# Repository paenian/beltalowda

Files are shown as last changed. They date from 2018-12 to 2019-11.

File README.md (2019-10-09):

# beltalowda
Large Beltesian 3D printer - that is a cartesian with a belt-driven Z axis.

# Status: Working! in testing.

# Todo:
 - Top Rail - add a top rail on the other end of the Y beam, and double-up the X axis motors.  While it works, the machine isn't rigid enough at the top end of the Y rail.  Works fine for ~100mm tall parts, but more would be better.
 
 - Thicker bed surface, test other surfaces - the bed isn't quite rigid enough.  Making it thicker should help.  Joining, bending and moving a thicker belt aren't the easiest, but hopefully there's a happy mediun somewhere.

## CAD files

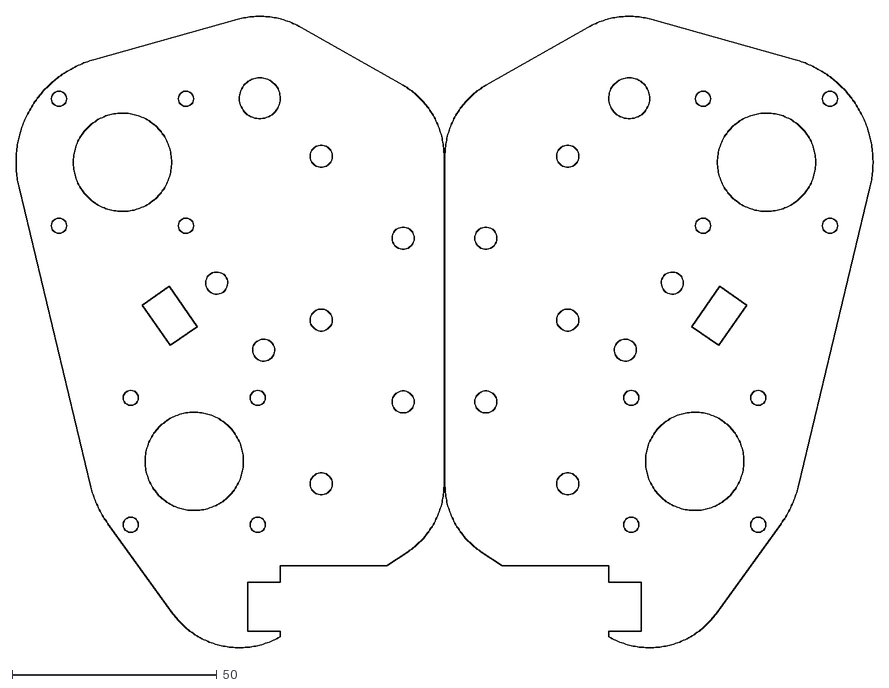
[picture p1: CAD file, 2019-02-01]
dxfs/spacer_plates.dxf
209.3 x 154.2

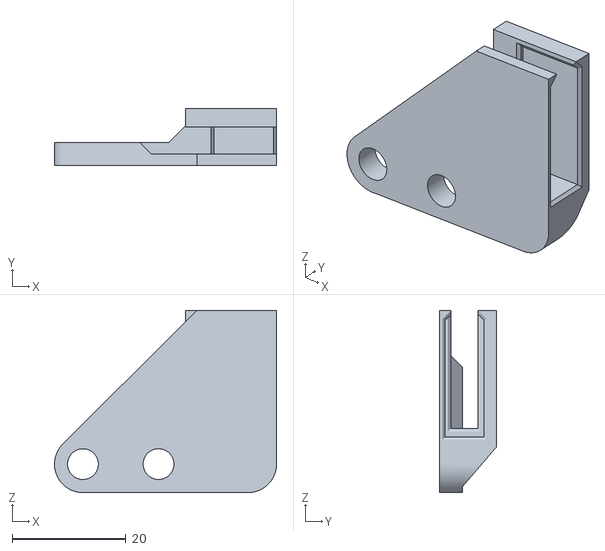
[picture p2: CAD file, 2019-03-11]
external_stls/endstop_mount.stl
39.0 x 10.0 x 32.0

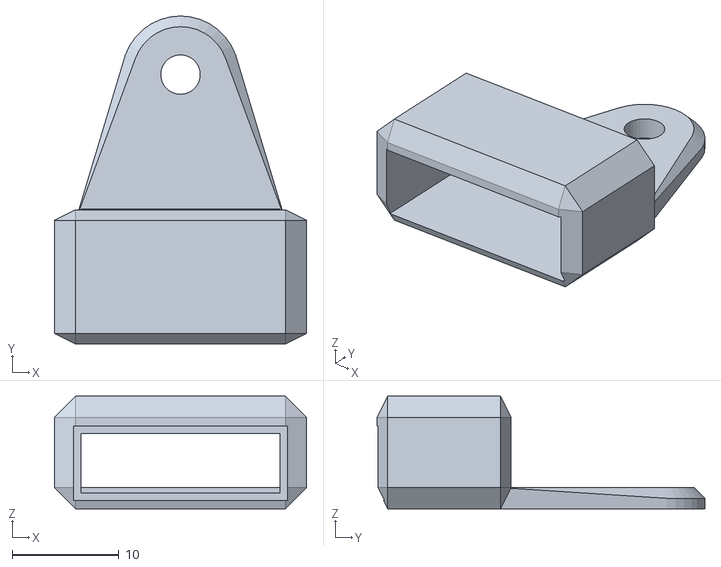
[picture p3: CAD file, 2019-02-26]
stls/endstop_mount.stl
23.7 x 30.8 x 10.6

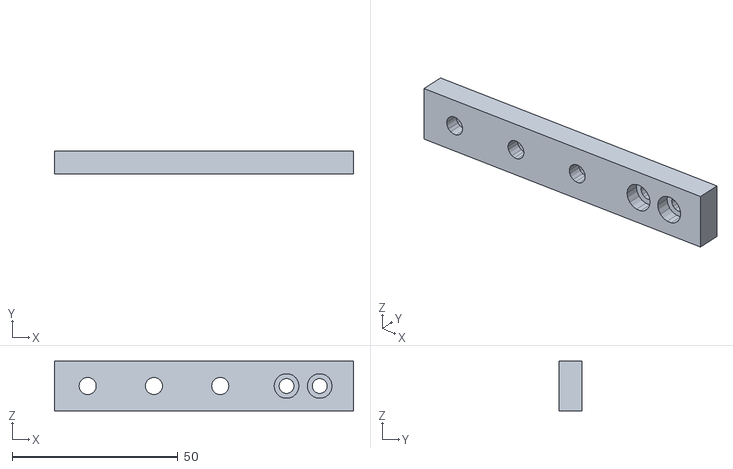
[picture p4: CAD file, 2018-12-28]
temp_stls/power_mount.stl
90.2 x 6.90 x 15.0

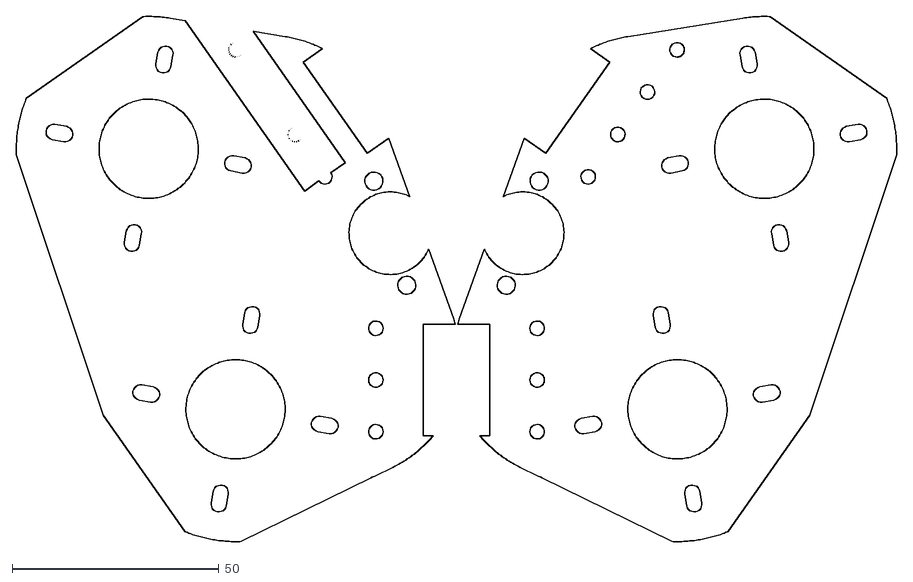
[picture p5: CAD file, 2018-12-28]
dxfs/y_plates.dxf
212.9 x 127.0

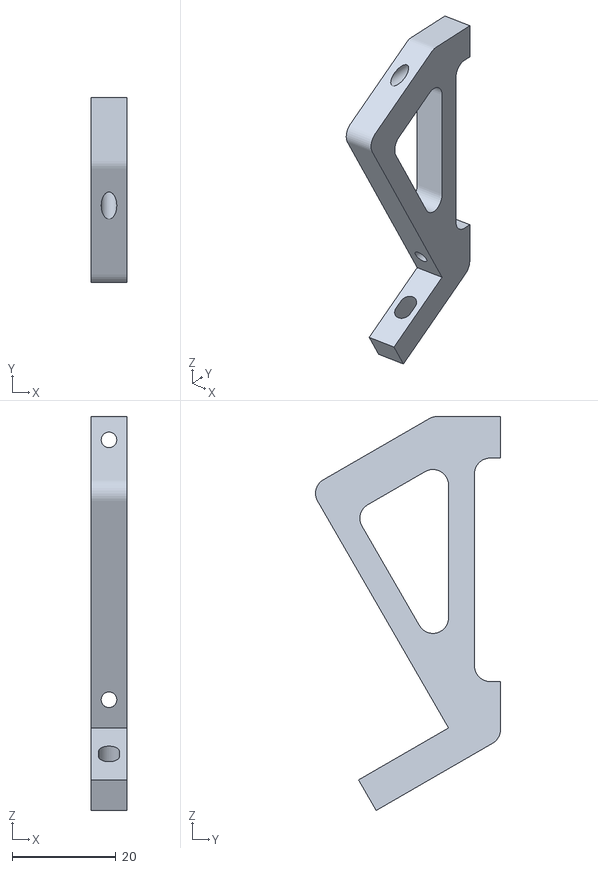
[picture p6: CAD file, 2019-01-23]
external_stls/Smart_LCD_kinnitus.stl
7.00 x 35.6 x 75.8

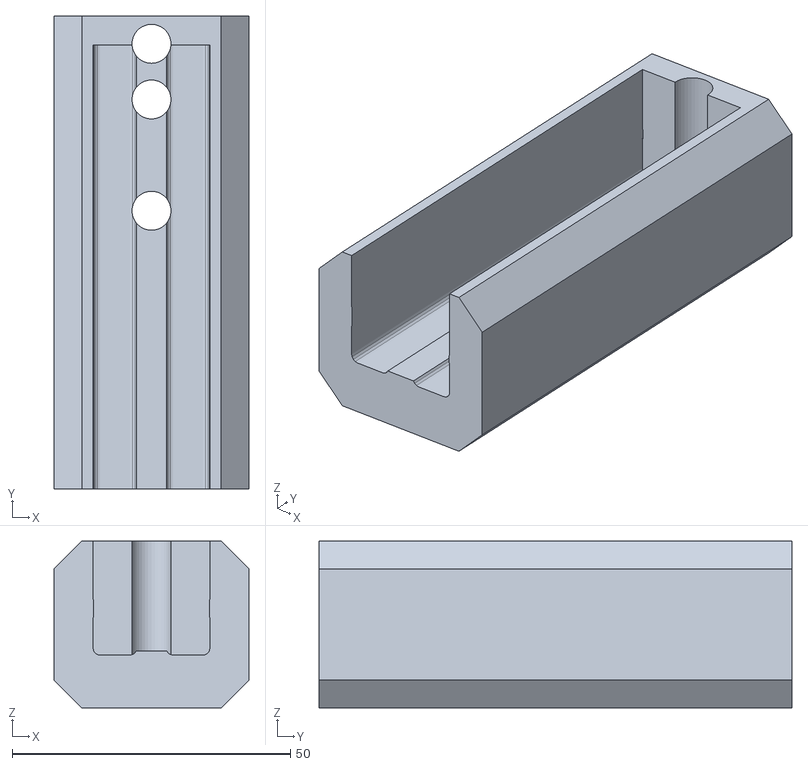
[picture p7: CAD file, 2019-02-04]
stls/drill_guide.stl
35.0 x 85.0 x 30.0

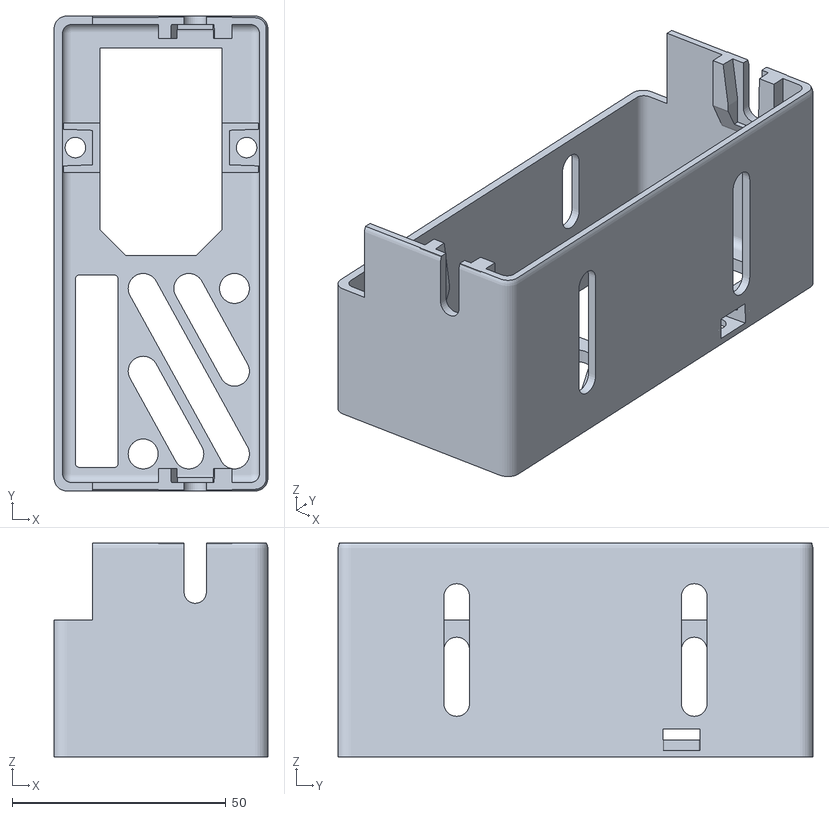
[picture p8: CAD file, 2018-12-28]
temp_stls/PowerSupply.stl
50.0 x 111.0 x 50.0

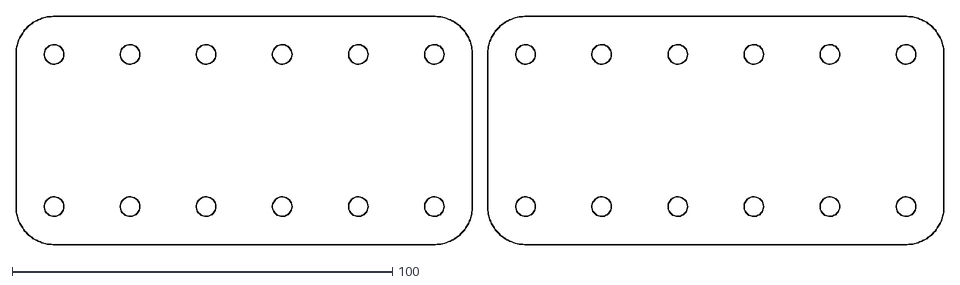
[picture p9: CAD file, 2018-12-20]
dxfs/bed_plate.dxf
244.0 x 60.0

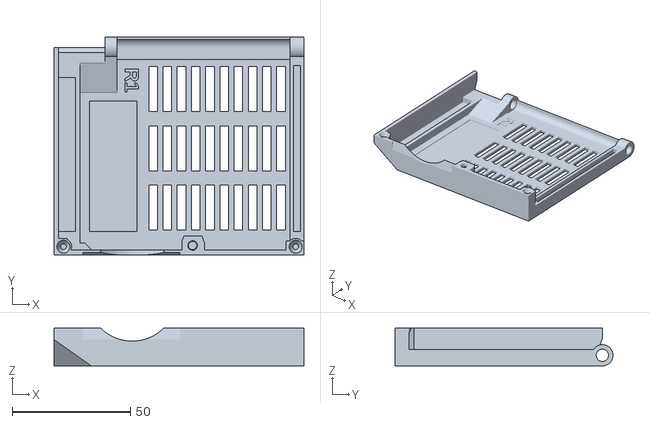
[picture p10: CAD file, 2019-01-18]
external_stls/Einsy_Door_with_fan.stl
105.5 x 92.0 x 16.0

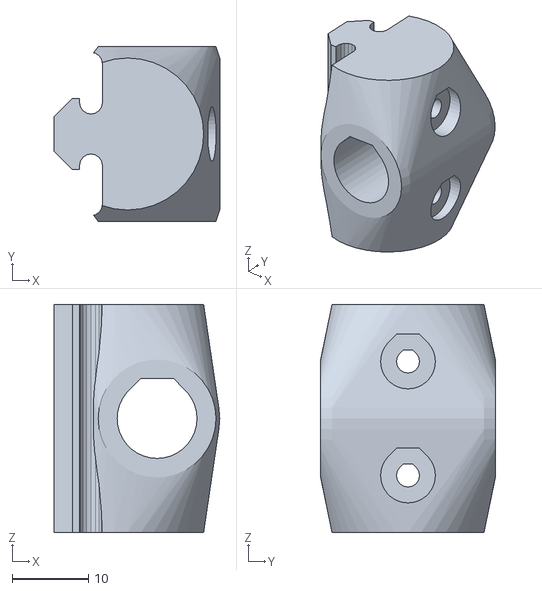
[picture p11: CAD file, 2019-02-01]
stls/z_slider.stl
21.8 x 23.0 x 30.0

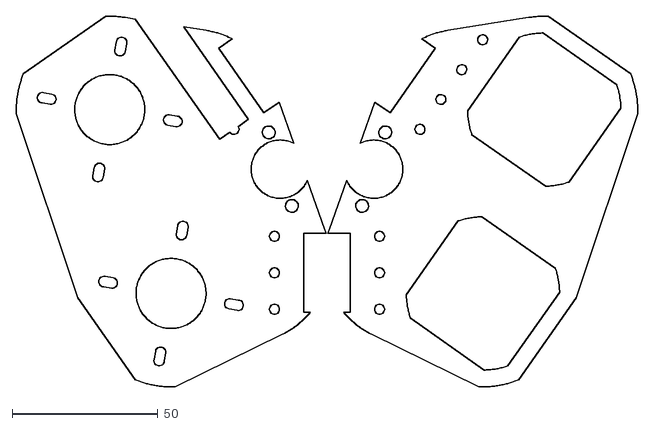
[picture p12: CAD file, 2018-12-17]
dxfs/ab2_y_plates.dxf
212.9 x 127.0

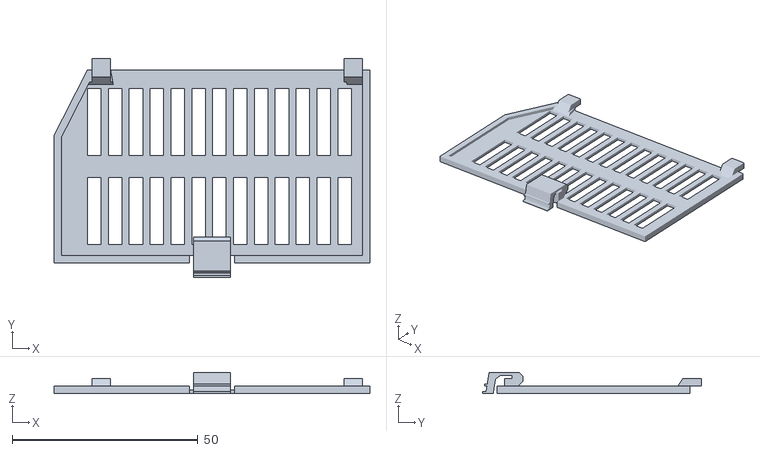
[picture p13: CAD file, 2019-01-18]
external_stls/New_Pi_Zero_Door.STL
85.0 x 58.9 x 5.66

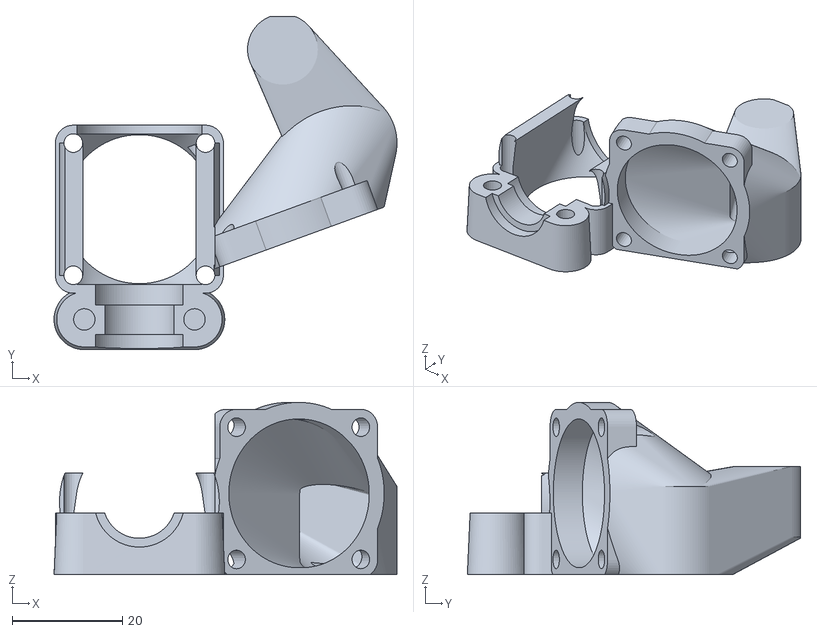
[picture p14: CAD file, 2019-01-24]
stls/hotend_fan_mounts.stl
62.2 x 60.5 x 31.2

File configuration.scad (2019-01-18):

in = 25.4;
mdf_wall = 6.5;
mdf_tab = 15;

wall = 5;

screw_slop = .2;
slop = .2;
laser_slop = -.1;

beam = 20;

layer_height=.2;

pulley_rad = 13/2;
pulley_flange_rad = 18/2;

//bed thicknesses
bed_inset = 4;
bed_thick = 2.3;
heater_thick = 2.2;
insulation_thick = 1;
bed_lift = heater_thick+insulation_thick;

eccentric_rad = 7.3/2;
eccentric_flange_rad = 11/2;

belt_thick = 9;
belt_width = 1.5;

//belt drive variables
small_teeth = 13;
motor_shaft_rad = 5/2+.2;
big_teeth = 41;
gear_thick = 13;
distance_between_axles = 37;
circular_pitch = 360*distance_between_axles/(small_teeth+big_teeth);


//motor size and placement variables
motor_w = 42;
motor_r = 52/2;
motor_screw_sep = 31;

//standard screw variables
m3_nut_rad = 6.01/2+slop;
m3_nut_height = 2.4;
m3_rad = 3.1/2+slop;
m3_cap_rad = 3.5;
m3_cap_height = 2;
m3_sq_nut_rad = 7.9/2;

m4_nut_rad = 7.66/2+slop;
m4_nut_height = 3.2;
m4_rad = 4/2+slop;
m4_cap_rad = 7/2+slop;
m4_cap_height = 2.5;

m5_nut_rad = 8.79/2;
m5_sq_nut_rad = (8*sqrt(2)+slop/2)/2;
m5_nut_rad_laser = 8.79/2-.445;
m5_nut_height = 4.7;
m5_rad = 5/2+slop;
m5_rad_laser = 5/2-.1;
m5_cap_rad = 10/2+slop;
m5_cap_height = 3;
m5_washer_rad = 11/2+slop;

ten24_rad = (.19*in/2+slop);
ten24_cap_rad = (.361*in/2+slop);
ten24_cap_height = .101*in+slop;
ten24_nut_rad = ((3/8*in)*cos(180/6))/2;
ten24_sq_nut_rad = ((3/8*in)*sqrt(2))/2+slop/2;

ten24_nut_height = 1/8*in+slop;

ten24_rad_laser = ten24_rad+laser_slop/2;
ten24_sq_nut_rad_laser = ten24_sq_nut_rad+laser_slop/2;
ten24_sq_nut_flat = 9.5;
ten24_sq_nut_flat_laser = ten24_sq_nut_flat+laser_slop;

//x axis variables
linear_rail_width = 12;
linear_rail_height = 8;
linear_rail_carriage_width = 27;
linear_rail_carriage_height = 10;
linear_rail_carriage_length = 34.7;
linear_rail_carriage_offset = 3+(linear_rail_carriage_height-linear_rail_height)/2;
linear_rail_carriage_screw_sep_w = 20;
linear_rail_carriage_screw_sep_l = 20;
linear_rail_screw_offset = 12.5;
linear_rail_screw_sep = 25;


//makes all the holes have lots of segments
$fs=.5;
$fa=.1;


//machine configuration parameters
y_rail_sep = 300;

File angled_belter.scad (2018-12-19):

include <configuration.scad>
use <functions.scad>
use <herringbone_gears.scad>

length = 500;
angle = 35;

bed_plate = in*20;
roller_rad = 2.375/2*in;
roller_rod_rad = 5;
roller_drop = 1;
roller_len = in*14;
roller_offset_front = roller_rad+10;
roller_span = 340;
roller_inside_rad = 2.075/2*in-.05;


bearing_rad = 26/2+.125;
bearing_rad = 32/2+.125;    //switch everything to 12mm rods?  Or keep the rollers on 10mm?
bearing_thick = 8;
bearing_thick = 10;
bearing_inset = in;

//belt drive variables
small_teeth = 13;
motor_shaft_rad = 5/2+.2;
big_teeth = 41;
gear_thick = 13;
distance_between_axles = 37;
circular_pitch = 360*distance_between_axles/(small_teeth+big_teeth);

//x axis
x_rod_rad = 6;
x_rod_sep = motor_w+x_rod_rad*4;
x_bearing_flange = 31.5;
x_bearing_flange_rad = 42/2;
x_bearing_rad = 21/2;

back_flange_rad = 36.5/2;
back_nut_rad = 20/2;
back_screw_sep = 26.4;

//x_nut_rad = 10.3/2;
//x_nut_screw_rad = 16/2;

linear_rail_width = 12;
linear_rail_height = 8;




echo(big_teeth/small_teeth);

bracket_thick = 6;

z_rear_offset = 100;
bed_lift = roller_rod_rad+roller_rad; //in*1/16; //put a little insulation under the bed beams

chamfer = 1.5;

part = 5;
mirror = 0;

if(part == 1){
    echo("Print 2 sets of corner brackets");
    translate([beam+.5,0,0]) mirror([1,0,0]) side_bracket(feet=false, corner=true);
    translate([-beam-.5,0,0]) side_bracket(feet=false, corner=true);
}

if(part == 1.5){
    echo("Cut 2 sets of corner brackets");
    projection(){
        translate([beam+.5,0,0]) mirror([1,0,0]) side_bracket(feet=false, corner=true);
        translate([-beam-.5,0,0]) side_bracket(feet=false, corner=true);
    }
}

if(part == 2){
    echo("print both spacer plates");
    translate([-beam*2.4,0,0]) spacer_plate();
    mirror([1,0,0]) translate([-beam*2.4,0,0])  spacer_plate();
}

if(part == 2.5){
    echo("Lasercut both spacer plates");
    projection() {
        translate([-beam*2.355,0,0]) spacer_plate();
        mirror([1,0,0]) translate([-beam*2.355,0,0])  spacer_plate();
    }
}

if(part == 3){
    y_plate();
}

if(part == 3.5){
    projection() {
        translate([-beam*.5,0,0]) y_plate();
        mirror([1,0,0]) translate([-beam*.5,0,0]) y_plate(front=true);
    }
}

if(part == 33){
    y_plate(front = true);
}

if(part == 33.5){
    projection() y_plate(front = true);
}

if(part == 4){
    echo("Print 3 roller mounts!");
    mirror([0,0,1]) roller_mount();
}

if(part == 5){
    echo("Print 1 roller drive mounts!");
    mirror([0,0,1]) roller_drive_mount();
}

if(part == 6){
    echo("Print 1 roller drive gear!");
    mirror([0,0,1]) motor_drive_gear();
}

if(part == 7){
    echo("Print one y gantry");
    y_gantry();
}

if(part == 8){
    echo("Print one y endcap");
    endcap();
}

if(part == 9){
    echo("Print one extruder assembly");
    extruder();
}

if(part == 10){
    echo("Print 6ish feet");
    rubber_foot();
}

if(part == 11){
    echo("Print 4 12mm clamps");
    smooth_rod_clamp(rad = x_rod_rad);
}

if(part == 12){
    echo("Print 2 10mm clamps");
    smooth_rod_clamp(rad = rod_rad);
}


if(part == 100){
    assembled();
}
module assembled(){
    frame();
    
    #rods_and_rails();
    
    //side brackets
    *for(i=[0]) for(j=[0,1]) mirror([j,0,0])
        translate([-length/2-bracket_thick/2,i*(length/2-beam*3),0]) rotate([0,-90,0]) rotate([0,0,-90]) render() side_bracket(feet=true);
    
    //corner brackets
    for(i=[0,1]) for(j=[0,1]) mirror([j,0,0]) mirror([0,i,0])
        translate([-length/2-bracket_thick/2,length/2,beam]) mirror([i,0,0]) rotate([0,-90,0]) rotate([0,0,-90]) render() side_bracket(feet=true, corner=true);
    
    for(i=[0,1]) mirror([i,0,0]) translate([-length/2+beam+bracket_thick/2,0,beam*1.5]) rotate([0,90,0]) {
        render() spacer_plate();
    } 
    
    //y axis
    translate([0,x_offset,beam*1.5]) rotate([0,90,0]) {
        render() y_plate(front = false);
        render() translate([0,0,bracket_thick]) y_plate(front = true);
    }
}

module frame(){
    //base
    for(i=[0,1]) mirror([i,0,0]) translate([length/2-beam/2,-length/2,0]) rotate([0,90,0]) rotate([-90,0,0]) render() beam_2060(height = length, v=false);
      
      //don't think this is necessary - the feet will handle the separation.  Or maybe should have this, but no feet...
    for(i=[0,1]) mirror([0,i,0]) translate([-length/2,length/2+beam/2,0]) rotate([0,90,0]) rotate([0,0,0]) render() beam_2060(height = length, v=false);
        
    //bottom 'feet'
    *for(i=[-1,0,1]) translate([-length/2,i*length/2,-beam*2]) rotate([90,0,0]) rotate([0,90,0]) render() beam_2040(height = length, v=false);
    
    //bed beams
    for(j=[1.5]) for(i=[0:6]) translate([-length/2,roller_offset_rear+roller_rad+beam+i*beam*2,beam*2*j]) rotate([90,0,0]) rotate([0,90,0]) render() beam_2040(height = length, v=false);
}

module smooth_rod_clamp(rad = 5, inset=.125){
    screw_sep  = rad + m5_cap_rad;
    screw_height = 9;
    echo(wall);
    difference(){
        union(){
            translate([0,0,rad]) rotate([90,0,0]) hull(){
                cylinder(r=rad+wall, h=beam-2, center=true);
                cylinder(r=rad+wall-1, h=beam, center=true);
            }
            
            for(i=[0,1]) mirror([i,0,0]) translate([screw_sep,0,0]) hull() {
                cylinder(r=m5_rad+wall, h=screw_height+1);
            }
        }
        
        rotate([90,0,0]) hull(){
            cylinder(r=rad+slop, h=beam+1, center=true);
            translate([0,rad,0]) rotate([0,0,180]) cap_cylinder(r=rad+slop, h=beam+1, center=true);
        }
        
        //screwholes
        for(i=[0,1]) mirror([i,0,0]) translate([screw_sep,0,0]) {
            cylinder(r=m5_rad+slop, h=screw_height*3, center=true);
            translate([0,0,screw_height]) cylinder(r=m5_cap_rad+slop, h=wall*3);
        }
        
        //flatten the bottom
        translate([0,0,-50+inset]) cube([100,100,100], center=true);
    }
}

//this goes on the end of the Y axis and tensions the belt.
module endcap(length = 29){
    min_rad = wall/2;
    difference(){
        union(){
            minkowski(){
                cube([linear_rail_width+wall, linear_rail_height+wall, length+wall], center=true);
                sphere(r=min_rad, $fn=6);
            }
            
            //belt pulley mount
            translate([0,-linear_rail_height/2-wall/2,0]) rotate([90,0,0]) cylinder(r1=linear_rail_width/2+wall, r2=m5_rad+.75, h=wall+bracket_thick);
        }
        
        //rail cutout
        translate([0,0,-wall]) cube([linear_rail_width+slop*4, linear_rail_height+slop*4, length], center=true);
        
        //tensioner
        translate([0,0,length/2+wall]){
            translate([0,0,-wall*2+m5_nut_height+1+.25]) cylinder(r=m5_rad, h=length);
            
            translate([0,0,-wall*2]){
                cylinder(r1=m5_nut_rad+.25, r2=m5_nut_rad, h=m5_nut_height+1, $fn=6);
            
                //place to insert the nut
                hull(){
                    translate([0,0,-length-wall]) cylinder(r=m5_nut_rad+1, h=.1);
                    cylinder(r1=m5_nut_rad+.25, r2=m5_nut_rad, h=.1, $fn=6);
                }
            }
        }
        
        //belt nut and shaft
        translate([0,-linear_rail_height/2,0]) rotate([90,0,0]){
            cylinder(r1=m5_nut_rad+.25, r2=m5_nut_rad, h=m5_nut_height+1, $fn=6);
            
            //place to insert the nut
            hull(){
                translate([0,0,-linear_rail_height-wall]) rotate([0,0,180]) cap_cylinder(r=m5_nut_rad+1, h=.1);
                cylinder(r1=m5_nut_rad+.25, r2=m5_nut_rad, h=.1, $fn=6);
            }
            
            //shaft
            rotate([0,0,180]) cap_cylinder(r=m5_rad, h=50, center=true);
        }
    }
}
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

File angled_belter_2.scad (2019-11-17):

include <configuration.scad>
use <functions.scad>
use <herringbone_gears.scad>

length = 500;
angle = 35;

//roller variables
roller_rad = 2.375/2*in;
roller_rod_rad = 5;
roller_drop = 1;
roller_len = in*14;
roller_span = 340;
roller_inside_rad = 2.075/2*in-.075;

//roller bearings - 10mm rods right now.
bearing_rad = 26/2+.15;
//bearing_rad = 32/2+.125;    //switch everything to 12mm rods?  Or keep the rollers on 10mm?
bearing_thick = 8;
bearing_inset = in;

//roller drive variables
small_teeth = 13;
motor_shaft_rad = 5/2+.2;
big_teeth = 61;
gear_thick = 13;
distance_between_axles = 37;
circular_pitch = 360*distance_between_axles/(small_teeth+big_teeth);

//bracket variables
bracket_thick = 6;
chamfer = 1.5;

back_flange_rad = 36.5/2;
back_nut_rad = 20/2;
back_screw_sep = 26.4;

//extruder variables
screw_mount_rad = 5;
screw_mount_screw_sep = 20;

//positioning variables
x_rail_offset_rear = [0,-length/2-beam/2,0];
x_rail_offset_front = x_rail_offset_rear + [0,71,23];

roller_offset_rear = [0,x_rail_offset_front[1] + roller_rad+23,beam*1.5+roller_rod_rad];
roller_offset_front = [0,length/2-roller_rad-beam,beam*1.5+roller_rod_rad];

x_motor_offset = x_rail_offset_rear+[0,motor_w/2+linear_rail_width+wall/2,beam*1.5+motor_w/2];



y_beam_offset = x_motor_offset + [0,motor_w/2, motor_w/2];
y_beam_inset = 9;
y_motor_offset = [-motor_w/2-beam/2, motor_w/2, 0];
y_pulley_offset = y_motor_offset[0];
//The Motor is dependent on the beam - this is an offset from the beam.
y_bracket_hole_lift = linear_rail_carriage_height+14.5;

bed_height = roller_rad+roller_rod_rad+3;
bed_height = beam*2;
bed_offset_rear = -89;

extruder_offset = y_beam_offset - [0,motor_w*1.5,motor_w/2];

part = 21;

if(part == 1){
    projection(){
        rotate([0,90,0]) translate([-length/2+beam,0,beam/2+.1]) spacer_plate_drive();
        rotate([0,-90,0]) translate([length/2-beam,0,beam/2+.1]) spacer_plate_drive();
    }
}

if(part == 2){
    projection(){
        rotate([0,90,0]) translate([-length/2+beam,0,-35]) y_plate(front = false);
        rotate([0,-90,0]) translate([length/2-beam,0,-35]) y_plate(front = true);
    }
}

if(part == 9){
    projection(){
        translate([beam*3.1,0,0]) bed_plate();
        translate([-beam*3.1,0,0]) bed_plate();
    }
}

if(part == 5){
    y_plate_bracket(shift = 0);
}

if(part == 6){
    y_plate_bracket(shift = 1);
}

if(part == 7){
    y_gantry();
    translate([0,16,-bracket_thick/2]) groovemount_screw_clamp();
}

if(part == 77){
    translate([0,16,-bracket_thick/2]) groovemount_clamp_fan();
}

if(part == 8){
    y_tensioner();
}

if(part == 10){
    bed_clamp();
}

if(part == 11){
    bed_rear_support();
}

if(part == 12){
    bed_front_support();
}

if(part == 20){
    mirror([0,0,1]) roller_drive_mount();
}

if(part == 21){
   mirror([0,0,1]) motor_drive_gear();
}

if(part == 22){
    mirror([0,0,1]) roller_mount();
}

if(part == 100){
    assembled();
}

module assembled(){
    frame();
    
    rods_and_rails();
    
    //corner brackets
    for(i=[0,1]) for(j=[0,1]) mirror([j,0,0]) mirror([0,i,0])
        translate([-length/2-bracket_thick/2,length/2,beam]) mirror([i,0,0]) rotate([0,-90,0]) rotate([0,0,-90]) render() side_bracket(feet=true, corner=true);
    
    spacer_plate_drive();
    spacer_plate_idler();
    
    //y axis
    translate([0,x_offset,beam*1.5]) rotate([0,90,0]) {
        render() y_plate(front = false);
        render() translate([0,0,bracket_thick]) y_plate(front = true);
    }
}

module frame(){
    //base square
    for(i=[0,1]) mirror([i,0,0]) translate([length/2-beam/2,-length/2,0]) rotate([0,90,0]) rotate([-90,0,0]) render() beam_2060(height = length, v=false);
    for(i=[0,1]) mirror([0,i,0]) translate([-length/2,length/2+beam/2,0]) rotate([0,90,0]) rotate([0,0,0]) render() beam_2060(height = length, v=false);
    
    //bed beams
    for(i=[0:6]) translate([-length/2,bed_offset_rear+i*40,bed_height+beam]) rotate([90,0,0]) rotate([0,90,0]) render() beam_2040(height = length, v=false);
}

module rods_and_rails(solid = 0, z_rollers=true, draw_y_beam = true){
    //x rails
    translate(x_rail_offset_rear+[0,0,beam*1.5+linear_rail_height/2]) rotate([0,90,0]) rotate([0,0,90]) linear_rail();
    translate(x_rail_offset_front+[0,0,beam*1.5+linear_rail_height/2]) rotate([0,90,0]) rotate([0,0,90]) rotate([0,0,angle]) {
        linear_rail();
        translate([-beam/2,-beam/2-linear_rail_height/2,-(length-beam*2-bracket_thick*2-1)/2]) {
            beam_2040(height = length-beam*2-bracket_thick*2-1);
            //beam screwholes
            for(i=[-beam/2, beam/2]) translate([i,0,-beam*2]) cylinder(r=m5_rad, h=length+beam);
        }
    }
    
    //x axis
    translate(x_motor_offset) rotate([0,90,0]) {
        cylinder(r=4, h=length, center=true);
        if(solid != 1) {
            for(i=[0,1]) mirror([0,0,i]) translate([0,0,length/2-beam]) motor_holes(slot=0);
            
            translate([0,0,bracket_thick]) mirror([0,0,1]) rotate([0,0,90+angle/2]) backlash_nut();           
        }
    }
    
    //y axis   
    translate(y_beam_offset) rotate([0,90,0]) rotate([0,0,angle]) {
        if(solid != 1) {
            //y rail
            translate([0,length/2-y_beam_inset,0]) rotate([90,0,0]) linear_rail(solid = solid, beam = draw_y_beam);
            %translate([0,motor_w+37,0]) rotate([0,0,-90]) y_gantry();
            
            translate(y_motor_offset) motor_holes(slot=0);
        }
    }
    
    //z rollers
    if(z_rollers == true){
        for(i=[roller_offset_rear,roller_offset_front]) translate(i) rotate([90,0,0]) rotate([0,90,0]) {
            cylinder(r=roller_rad, h=roller_len, center=true);
            cylinder(r=roller_rod_rad, h=length, center=true);
        }
    
        //z motor
        z_angle = 25;
        translate(roller_offset_rear+[length/2-beam,0,0])
        rotate([z_angle,0,0]) translate([0,0,distance_between_axles]) rotate([-z_angle,0,0])
        rotate([0,90,0]) motor_holes(slot=0);
    }
    
    echo("roller sep = ");
    echo(roller_offset_front - roller_offset_rear);
    echo("Belt Length = ");
    echo((roller_offset_front - roller_offset_rear)[1] * 2 + 2*3.14159*roller_rad);
}


module motor_drive_gear(){
    translate([distance_between_axles+1,0,0]) gear1(gear1_teeth = small_teeth, circular_pitch=circular_pitch, gear_height=gear_thick);
}

module roller_drive_mount(wall = 3){
    %motor_drive_gear();
    
    radius = gear_radius(big_teeth, circular_pitch);
    outer_radius = gear_outer_radius(big_teeth, circular_pitch);
    
    gear_chamfer_radius = (outer_radius - radius) / tan(45);
    
    lift = gear_thick+1;
    
    difference(){
        union(){
            
            //roller mount
            translate([0,0,lift-.05]) roller_mount();
            //gear
            chamfered_herring_gear(height=gear_thick, number_of_teeth=big_teeth, circular_pitch=circular_pitch, teeth_twist=-1);
            //connect the two
            translate([0,0,gear_thick-.05]) cylinder(r1=radius, r2=roller_inside_rad+wall, h=lift-gear_thick+.1);
        }
        
        //hollow out a path upwards
        translate([0,0,-.1]) cylinder(r1=bearing_rad+wall*3, r2=bearing_rad+wall*2, h=lift+1);
        
        //reopen the tightener holes for the set screws
        translate([0,0,lift-.05]) for(i=[60:360/3:359]) rotate([0,0,i]) translate([0,0,wall*3]) {            
            //access hole
            rotate([0,0,0]) rotate([0,-90-13,0]) rotate([0,0,-90]) cap_cylinder(r=m5_rad+.5, h=50);
        }
    }
}
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

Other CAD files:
dxfs/ab2_spacer_plates.dxf
external_stls/Einsy-base_modified_with_door.stl
stls/roller_drive_gear.stl
dxfs/corner_bracket_pair.dxf
bdp.scad
belter.scad
cooling_fan_mount.scad
dxfs/side_plate.dxf
dxfs/y_front_plate.dxf
external_stls/rpi-zero-frame.stl
extrusion_mounts.scad
functions.scad
herringbone_gears.scad
stls/bed_front_support.stl
stls/bed_side_support.stl
stls/roller_mount.stl
stls/rubber_foot.stl
stls/spacer.dxf
stls/x_rod_slider.stl
stls/x_tensioner.stl
stls/y_bracket.stl
stls/y_bracket_shifted.stl
stls/y_gantry.stl
stls/y_tensioner.stl
temp_stls/power_mount.scad

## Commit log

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2018-08-29 Added side plates, playing with layout.
    [bdp.scad, side_bracket.stl]
2018-08-30 Added the Z brackt.
    At some point the center beam and Z brackets will be joined, but
    the distance isn't yet set in stone.
    [belter.scad, z_bracket.stl]
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2018-09-11 Updated side pulls; gotta make a compile script.
    [belter.scad, roller_mount.stl, side_bracket.stl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]
2018-09-17 Updated with larger rollers, all brackets, and a compiler
    [belter.scad, roller_fixed_l_bracket.stl, roller_fixed_r_bracket.stl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]
2018-09-24 Updated most of the belters
    [belter.scad, motor_drive_gear.stl, roller_fixed_l_bracket.stl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]
2018-09-25 Updated everything around 2060 side beams.
    Will need to update the belt and motor drive gears.
    [belter.scad, functions.scad, motor_drive_gear.stl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]
2018-10-15 updated the side mounts for 2060
    [belter.scad, motor_drive_gear.stl, roller_fixed_l_bracket.stl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]
2018-10-30 Thinking more on the angled version :-)
    [angled_belter.scad, belter.scad]
2018-10-30 Updated side plates - to mount the X and Z axes.
    next: big old central Y axis mount
    add endstop mount to side plate
    [angled_belter.scad, functions.scad]
2018-11-03 working on it :-)
    [angled_belter.scad]
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2018-11-06 Added dxfs of the prototype plates
    [angled_belter.scad, side_plate.dxf, y_plate.dxf]
2018-11-07 Updated the corners, toying with z motor placement
    [angled_belter.scad, corner_L_bracket.stl, corner_R_bracket.stl]
2018-11-08 Mostly cleanup on the angler
    [angled_belter.scad]
2018-11-09 Updated the plates, lasercut files
    [angled_belter.scad, side_plate.dxf, y_plate.dxf]
2018-11-10 Working on the carriage
    [angled_belter.scad, corner_bracket_pair.dxf, corner_bracket_pair.stl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]
2018-11-12 Fixed the rod holes - updated sizing
    [angled_belter.scad, cooling_fan_mount.scad, functions.scad]
2018-11-13 Updated all compiled files
    [angled_belter.scad, corner_bracket_pair.dxf, corner_bracket_pair.stl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]
2018-11-14 Updated the assembly reference; all parts added.
    And it looks good!
    Todo:
    roller tensioner
    add belt tensioner to y gantry
    y belt end?
    rod clamps
    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
    [angled_belter.scad]
2018-11-15 Recompiled, added the endcap for the Y axis
    [angled_belter.scad, corner_bracket_pair.dxf, corner_bracket_pair.stl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]
2018-11-15 Fixed the side plates, cleaned up a smidge.
    [angled_belter.scad, shark_tooth_half.stl, smilodon_half.stl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]
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2018-11-19 Copying to clean... and reorient all the parts.
    Need to change the gantry style entirely, not as simple as it was
    - linear rails everywhere, with supports as needed :-0
    [angled_belter.scad, angled_belter_2.scad]
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2018-11-21 side plates redone, need to get the y plates
    [angled_belter_2.scad]
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2018-12-13 added some y brackets, updated the gantry and tensioner
    [angled_belter_2.scad, y_brace_3.stl, y_brace_4.stl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]
2018-12-16 reconfigured the y plates, shrunk the y axis offset.
    The motor shafts aren't long enough to span two MFD sheets, so
    make a cutout in one, mount motor in the other.
    Also started working on the main belt tensioner, in the
    extrusion_mounts.scad - plan to use eye bolts, springs, a sliding
    rod mount and a beefy seat at the end.
    Paul
    [ab2_y_plates.dxf, angled_belter_2.scad, configuration.scad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]
2018-12-16 Full prototype on the belt tensioner ready :-)
    Using eye bolts tied to springs on the rod sliders, with a brass
    knurled nut tensioning. A small oversight, I need to make a bed
    mount! Right now the idea is just to use a simple lasercut panel,
    so I've put off the design cuz it's easy and the lasercutter is
    far away.
    [belt_tensioner.stl, extrusion_mounts.scad]
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2018-12-18 re-added the double plates for the motors
    the extended shafts work if I arrange it oddly :-)
    [angled_belter_2.scad, y_plates.dxf]
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2018-12-18 y gantry was messed up... bad design!
    I copied some old code in, todo is to fix that :-/
    But it works for now.
    [angled_belter_2.scad, y_gantry.stl]
2018-12-18 added a spacer for the y axis rail
    [angled_belter_2.scad, configuration.scad, extrusion_mounts.scad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]
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2018-12-20 Updated the compile script... so I regenerated everything :-)
    Next up is a dose of cleanup.
    [angled_belter_2.scad, roller_drive_gear.stl, roller_mount.stl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]
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2018-12-28 Lots of edits and adds - mainly on securing the build plate.
    Starting to add the furniture, i.e. mounting less essential parts
    so, got some feet, power mount, added lock screws for the rollers,
    and regenerated pretty much everything
    [PowerSupply.stl, angled_belter_2.scad, belt_tensioner.stl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]
2019-01-16 Changed the gear ratio on the rollers - need more torque! Paul
    [angled_belter_2.scad, herringbone_gears.scad, roller_drive_gear.stl]
2019-01-18 Updated the bed supports, added einsy mount, bigger feet
    The power supply wouldn't fit! More feet, lol.
    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
    [Einsy-base_modified_with_door.stl, Einsy_Door_with_fan.stl, New_Pi_Zero_Door.STL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]
2019-01-21 working on extruder fan
    gonna need some endstop mounts, too, for 3mm screws :-(
    [angled_belter_2.scad, hotend_fan_mounts.stl]
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2019-02-01 Updated the spacer plates; need to drive both sides.
    [angled_belter_2.scad, extrusion_mounts.scad, spacer_plates.dxf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]
2019-02-04 Added a drill guide for a different printer...
    [angled_belter_2.scad, drill_guide.stl]
2019-02-08 added an endstop mount
    endstopless homing doesn't seem accurate enough for bed
    height, anyways
    [endstop_mount.stl, extrusion_mounts.scad]
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
